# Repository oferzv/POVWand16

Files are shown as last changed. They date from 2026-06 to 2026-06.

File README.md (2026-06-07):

# POVWand16

POVWand16 is a 16 LED persistence-of-vision wand. When the wand is moved
through the air, the firmware flashes a vertical column of LEDs fast enough
that the viewer sees complete text or simple bitmap graphics suspended in the
motion path.

The repository contains both sides of the project:

- Arduino firmware for driving the LED column and selecting messages or
  graphics.
- Autodesk Eagle schematic and board layout files for the custom PCB.
- Manufacturing outputs, including a BOM spreadsheet and Gerber archive.

## Project Overview

The design is based around an Arduino Nano-compatible controller connected to
16 individual LEDs. Each LED has its own 100 ohm series resistor. The firmware
writes directly to the AVR port registers for speed, allowing all 16 LEDs to be
updated as a two-byte column pattern.

A trigger input on Arduino analog pin A4 is used to step through the available
display content. The current firmware alternates between text messages and
graphics. Text can be rendered with either the English font table or the Hebrew
font table stored in program memory.

The hardware is intended to be a self-contained handheld wand. The PCB includes
the Arduino Nano footprint, the LED column, a 9 V battery holder, a power slide
switch, a tactile switch, and several header connectors.

## Repository Layout

```text
.
+-- Firmware
|   +-- README.md
|   +-- POVWand16_SW_heb
|       +-- POVWand16.ino
|       +-- font.h
|       +-- python
|           +-- pandaTestFormat.py
+-- Hardware
|   +-- V1_1
|       +-- Eagle
|       |   +-- POVWand16.brd
|       |   +-- POVWand16.sch
|       +-- Manufacturing
|           +-- BOM
|           |   +-- POVWand16_BOM.xlsx
|           +-- Gerber
|               +-- POVWand16_2020-03-09.zip
+-- README.md
```

## Hardware

The hardware design files live under `Hardware/V1_1`.

Main board elements:

- Arduino Nano 3.0-compatible module footprint.
- 16 through-hole 3 mm LEDs labeled `D1` through `D16`.
- 16 through-hole 100 ohm LED current-limiting resistors labeled `R1` through
  `R16`.
- 9 V battery holder footprint.
- Slide power switch.
- 6 mm momentary tactile switch.
- Additional 1x08 and 1x18 headers for board connections and expansion.

The Eagle files are:

- `Hardware/V1_1/Eagle/POVWand16.sch` - schematic.
- `Hardware/V1_1/Eagle/POVWand16.brd` - PCB layout.

Manufacturing files are:

- `Hardware/V1_1/Manufacturing/BOM/POVWand16_BOM.xlsx` - bill of materials.
- `Hardware/V1_1/Manufacturing/Gerber/POVWand16_2020-03-09.zip` - Gerber
  output for PCB fabrication.

## Firmware

The firmware is an Arduino sketch located at:

```text
Firmware/POVWand16_SW_heb/POVWand16.ino
```

Supporting files:

- `font.h` contains the English and Hebrew font tables in `PROGMEM`.
- `python/pandaTestFormat.py` is a small helper script for converting Hebrew
  text into the character order/encoding expected by the sketch.

The sketch uses Arduino pins 2 through 17 as the 16 LED outputs:

```cpp
const byte LEDpins[] = {2, 3, 4, 5, 6, 7, 8, 9, 10, 11, 12, 13, 14, 15, 16, 17};
```

The trigger input is on pin 18, which corresponds to Arduino A4:

```cpp
const byte triggerPin = 18;
```

Display timing is controlled by three constants:

- `charDelay` - spacing between characters.
- `tColDelay` - spacing between text columns.
- `gColDelay` - spacing between graphic columns.

The current firmware defines six text messages and two graphics. A trigger
press advances through the text messages, then advances through the graphics,
then returns to the first text message.

## Display Content

Text messages are defined in `POVWand16.ino` as `PROGMEM` strings:

```cpp
const char textString01 [] PROGMEM = "ARDIUNO - fqjafdya";
const char textString02 [] PROGMEM = "eqfyfxe jyha eay{q";
const char textString03 [] PROGMEM = "BRAVO!";
const char textString04 [] PROGMEM = "Hello";
const char textString05 [] PROGMEM = "WOW!";
const char textString06 [] PROGMEM = "Amazing";
```

Each message is paired with a font type in the `messages_new` table:

- `HEBFONT` selects the Hebrew font table.
- `ENGFONT` selects the English font table.

Graphics are stored as byte arrays in the `graphic` table. Each displayed
column is represented by two bytes, covering the full 16 LED height.

## Building and Uploading

Open `Firmware/POVWand16_SW_heb/POVWand16.ino` in the Arduino IDE or another
Arduino-compatible build environment.

Recommended target:

- Board: Arduino Nano or compatible.
- Processor: the option matching the installed Nano bootloader.
- Upload method: standard USB serial upload through the Nano.

After upload, power the wand and move it through the air. Use the trigger input
to cycle through the stored text and graphic displays.

## Customization Notes

To change displayed text:

1. Edit the `textStringXX` constants in `POVWand16.ino`.
2. Set each message's font type in `messages_new`.
3. Update `NUMBER_OF_ELEMENTS` if the number of messages changes.

To change graphics:

1. Edit the byte arrays in the `graphic` table.
2. Keep each graphic encoded as pairs of bytes per column.
3. Adjust the timing constants if the image appears stretched or compressed
   while waving the wand.

To change LED wiring:

1. Update `LEDpins` if using the slower `digitalWrite` helper path.
2. Update `setPorts()` if changing the direct AVR port mapping used by the
   main display loop.

## Attribution

The firmware is based on the JolliPOV Stick Arduino code from the Instructables
project
[Arduino Based POV Display Stick - JolliPOV Stick](https://www.instructables.com/Arduino-Based-POV-Display-Stick-JolliPOV-Stick/)
by [jollifactory](https://www.instructables.com/member/jollifactory/).

Credit and thanks to the original author for publishing the JolliPOV Stick
project instructions and example firmware.

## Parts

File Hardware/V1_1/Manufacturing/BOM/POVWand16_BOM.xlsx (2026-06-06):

povTest BOM
# | Qty | Parts | MF | MPN | PRICE | TOTAL | VALUE | FOOTPRINT | DESCRIPTION
1 | 1 | SW1 | C&K | PTS645SM43-2 LFS | $0.040 | $0.04 |  | 6.00mm x 6.00mm | SWITCH TACTILE SPST-NO 0.05A 12V | https://www.taydaelectronics.com/electromechanical/switches-key-pad/tact-switch/tact-switch-6-6mm-7mm-through-hole-spst-no-1.html
2 | 16 | R1, R2, R3, R4, R5, R6, R7, R8, R9, R10, R11, R12, R13, R14, R15, R16 |  |  | $0.012 | $0.19 | 100Ohm | T/H |  | https://www.taydaelectronics.com/resistors/1-4w-metal-film-resistors/test-group-2.html
3 | 16 | D1, D2, D3, D4, D5, D6, D7, D8, D9, D10, D11, D12, D13, D14, D15, D16 |  |  | $0.02 | $0.32 | 3mm | RADIAL 3MM |  | https://www.taydaelectronics.com/leds/round-leds/3mm-leds/led-3mm-red.html
4 | 2 |  |  |  | $0.12 | $0.24 |  |  | 15 PIN 2.54MM SINGLE ROW FEMALE PIN HEADER | https://www.taydaelectronics.com/connectors-sockets/pin-headers/15-pin-2-54-mm-single-row-female-pin-header.html
5 | 1 | M1 |  |  | $3.690 | $3.69 |  |  | NANO 3.0 CONTROLLER COMPATIBLE WITH ARDUINO NANO CH340 USB DRIVER | https://www.taydaelectronics.com/nano-3-0-controller-compatible-with-arduino-nano-ch340-usb-driver.html
6 | 1 | BT1 | MPD _Memory | BH9VPC | $0.470 | $0.47 |  |  | Battery Holder _Open_ 9V 1 Cell PC Pin | https://www.taydaelectronics.com/9v-battery-holder-6.html
7 | 1 | S1 |  | SS12F44G5 | $0.050 | $0.05 |  |  | SLIDE SWITCH 1P2T THROUGH HOLE 0.5A 50VDC | https://www.taydaelectronics.com/electromechanical/switches-key-pad/slide-switch/slide-switch-1p2t-through-hole-0-5a-50vdc.html
 |  |  |  |  |  | $5.00

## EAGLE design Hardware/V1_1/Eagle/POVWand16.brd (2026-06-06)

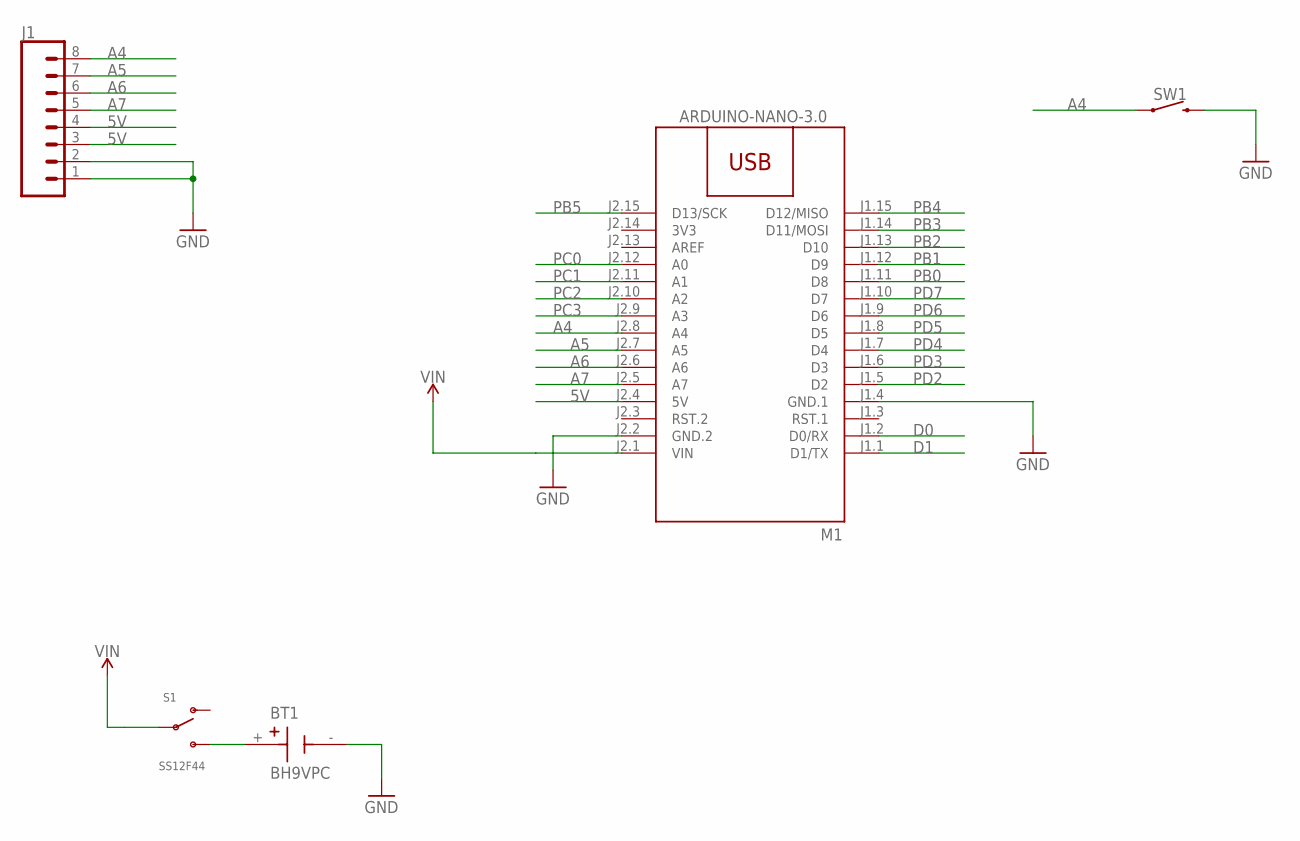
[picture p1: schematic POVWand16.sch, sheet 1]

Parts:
BT1: BH9VPC; BAT_BH9VPC
J1: CONN_08"; 1X08
M1: ARDUINO-NANO-3.0
S1: SS12F44; SS12F44G5
SW1: MOMENTARY-SWITCH-SPST_6X6MM; TACT_SW_PTH_6.0MM

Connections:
3V3: M1.J2.14 (3V3)
5V: J1.3, J1.4, M1.J2.4 (5V)
A4: J1.8, M1.J2.8 (A4), SW1.1, SW1.2 (1)
A5: J1.7, M1.J2.7 (A5)
A6: J1.6, M1.J2.6 (A6)
A7: J1.5, M1.J2.5 (A7)
D0: M1.J1.2 (D0/RX); also elsewhere on the board
D1: M1.J1.1 (D1/TX); also elsewhere on the board
GND: BT1.-, J1.1, J1.2, M1.J1.4 (GND.1), M1.J2.2 (GND.2), SW1.3 (2), SW1.4 (2); also elsewhere on the board
unnamed: BT1.+, S1.3 (S)
PB0: M1.J1.11 (D8); also elsewhere on the board
PB1: M1.J1.12 (D9); also elsewhere on the board
PB2: M1.J1.13 (D10); also elsewhere on the board
PB3: M1.J1.14 (D11/MOSI); also elsewhere on the board
PB4: M1.J1.15 (D12/MISO); also elsewhere on the board
PB5: M1.J2.15 (D13/SCK); also elsewhere on the board
PC0: M1.J2.12 (A0); also elsewhere on the board
PC1: M1.J2.11 (A1); also elsewhere on the board
PC2: M1.J2.10 (A2); also elsewhere on the board
PC3: M1.J2.9 (A3); also elsewhere on the board
PD2: M1.J1.5 (D2); also elsewhere on the board
PD3: M1.J1.6 (D3); also elsewhere on the board
PD4: M1.J1.7 (D4); also elsewhere on the board
PD5: M1.J1.8 (D5); also elsewhere on the board
PD6: M1.J1.9 (D6); also elsewhere on the board
PD7: M1.J1.10 (D7); also elsewhere on the board
VIN: M1.J2.1 (VIN), S1.2

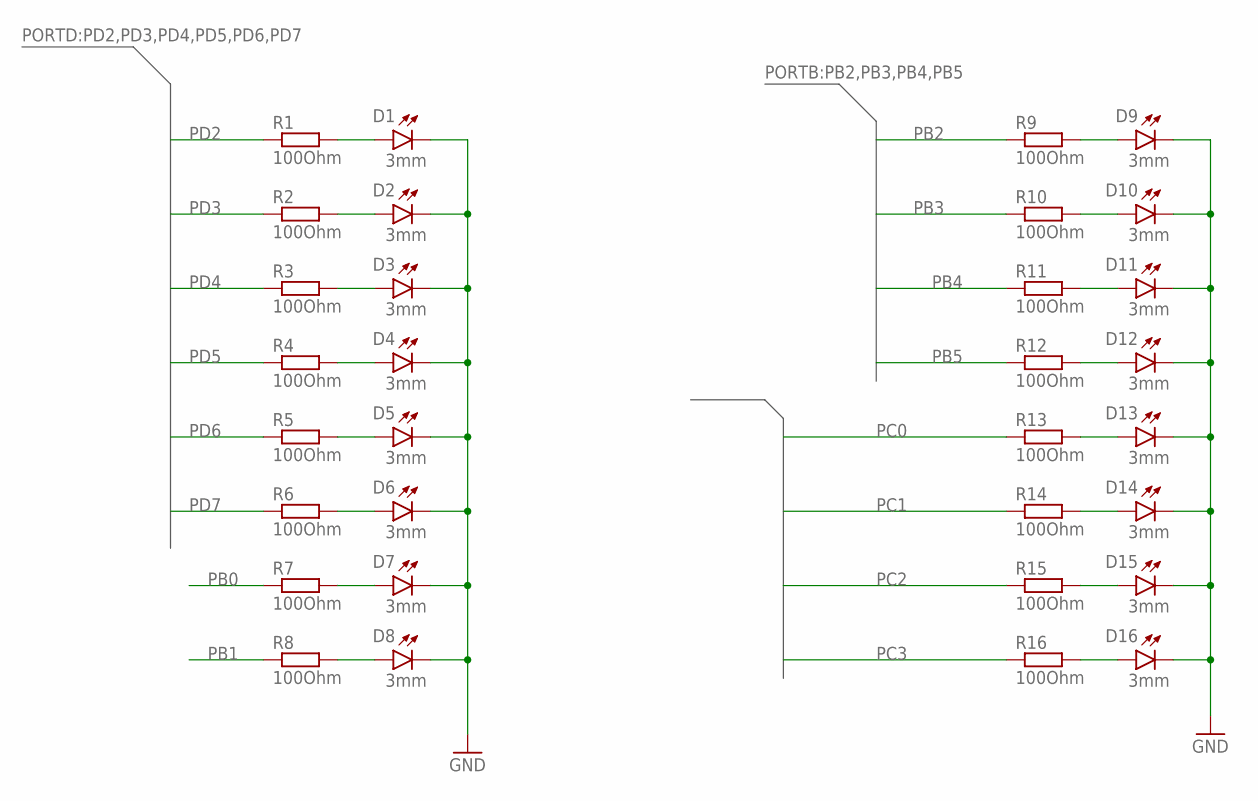
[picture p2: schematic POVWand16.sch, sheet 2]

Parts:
D1, D2, D3, D4, D5, D6, D7, D8, D9, D10, D11, D12, D13, D14, D15, D16: 3mm; LED3MM
R1, R2, R3, R4, R5, R6, R7, R8, R9, R10, R11, R12, R13, R14, R15, R16: 100Ohm; 0207/7

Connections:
GND: D1.K (C), D2.K (C), D3.K (C), D4.K (C), D5.K (C), D6.K (C), D7.K (C), D8.K (C), D9.K (C), D10.K (C), D11.K (C), D12.K (C), D13.K (C), D14.K (C), D15.K (C), D16.K (C); also elsewhere on the board
unnamed: D1.A, R1.2
unnamed: D2.A, R2.2
unnamed: D3.A, R3.2
unnamed: D4.A, R4.2
unnamed: D5.A, R5.2
unnamed: D6.A, R6.2
unnamed: D7.A, R7.2
unnamed: D8.A, R8.2
unnamed: D9.A, R9.2
unnamed: D10.A, R10.2
unnamed: D11.A, R11.2
unnamed: D12.A, R12.2
unnamed: D13.A, R13.2
unnamed: D14.A, R14.2
unnamed: D15.A, R15.2
unnamed: D16.A, R16.2
PB0: R7.1; also elsewhere on the board
PB1: R8.1; also elsewhere on the board
PB2: R9.1; also elsewhere on the board
PB3: R10.1; also elsewhere on the board
PB4: R11.1; also elsewhere on the board
PB5: R12.1; also elsewhere on the board
PC0: R13.1; also elsewhere on the board
PC1: R14.1; also elsewhere on the board
PC2: R15.1; also elsewhere on the board
PC3: R16.1; also elsewhere on the board
PD2: R1.1; also elsewhere on the board
PD3: R2.1; also elsewhere on the board
PD4: R3.1; also elsewhere on the board
PD5: R4.1; also elsewhere on the board
PD6: R5.1; also elsewhere on the board
PD7: R6.1; also elsewhere on the board

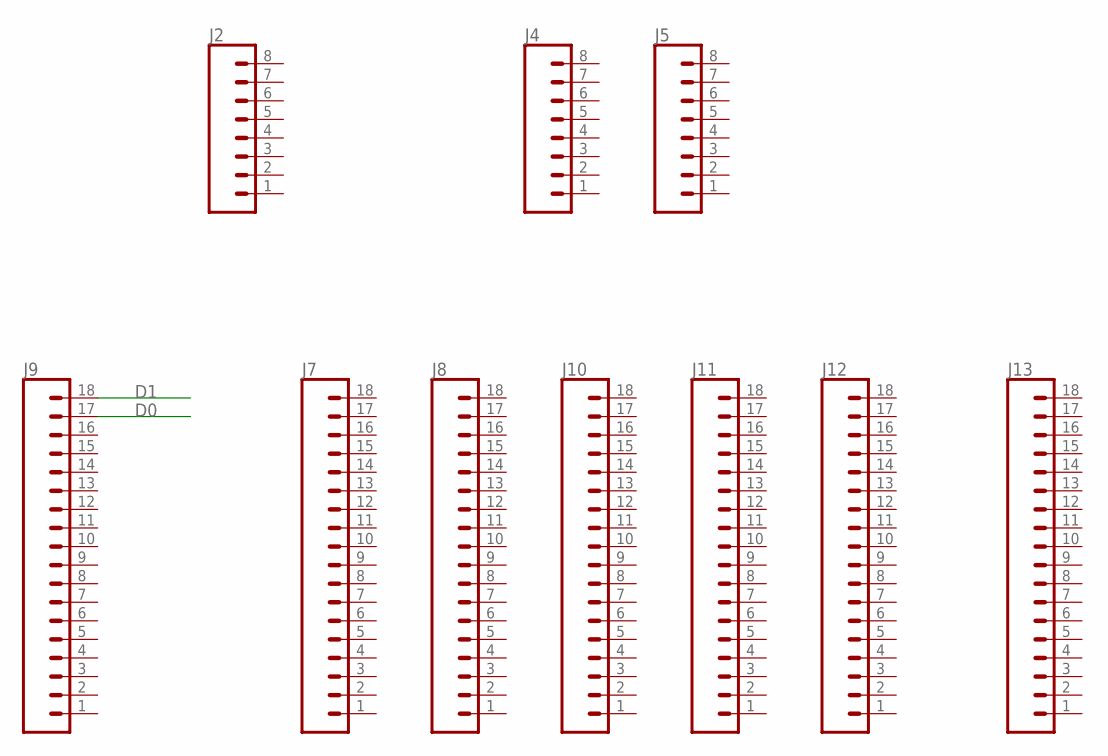
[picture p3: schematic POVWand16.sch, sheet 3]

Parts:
J2, J4, J5: CONN_08"; 1X08
J7, J8, J9, J10, J11, J12, J13: CONN_18; 1X18

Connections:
D0: J9.17; also elsewhere on the board
D1: J9.18; also elsewhere on the board

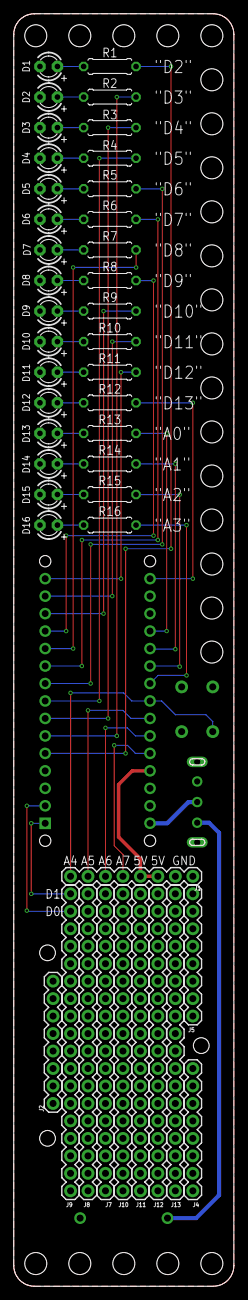
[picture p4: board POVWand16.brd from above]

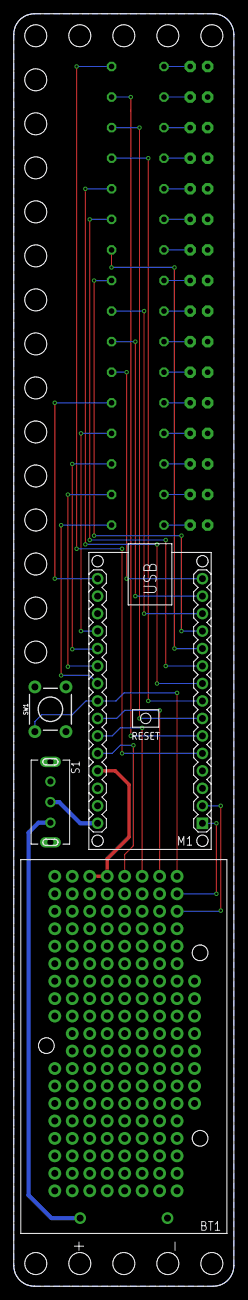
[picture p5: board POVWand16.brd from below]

Board: 2 copper layers, 32.0 x 185.0 mm, 47 parts (4 on the bottom side), 42 nets.

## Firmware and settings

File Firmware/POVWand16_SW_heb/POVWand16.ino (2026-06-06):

// Code Example for JF jolliPOV Stick kit example Demo #1 Ver 1.0

// This Arduino sketch works with JF jolliPOV Stick handheld and waving it to and forth to display text and graphics
// For this example, set jumper to position B for text and graphics display using Main PCB's 16 LEDs
// Checkout instructable available at https://www.instructables.com/id/Arduino-Based-POV-Display-Stick-JolliPOV-Stick/

#define HEBFONT 0
#define ENGFONT 1


byte NumberBytesChar = 21;
#include "font.h"

// Define the Arduino LED pins in use
const byte LEDpins[] = {2, 3, 4, 5, 6, 7, 8, 9, 10, 11, 12, 13, 14, 15, 16, 17}; // jolliPOV Stick Main PCB LED Pins

// Number of LEDs used
int LedCount() {
  return sizeof(LEDpins) / sizeof(*LEDpins);
}


// Define graphics 64 (Width) X 16 (Height)  ***********************************************************************************************************************
byte graphic[2][128] = {
  // Hearts 64 X 16
//  {
//    0x00, 0x00, 0xf0, 0x00, 0xf8, 0x01, 0x0c, 0x03, 0x06, 0x06, 0x06, 0x0c, 0x06, 0x18, 0x0c, 0x30, 0x18, 0x60, 0x0c, 0x30, 0x06, 0x18, 0x06, 0x0c, 0x06, 0x06, 0x0c, 0x03, 0xf8, 0x01, 0xf0, 0x00, 0x00, 0x00, 0x00, 0x00, 0xc0, 0x01, 0xe0, 0x03, 0xf0, 0x07, 0xf0, 0x0f, 0xe0, 0x1f, 0xc0, 0x3f, 0xe0, 0x1f, 0xf0, 0x0f, 0xf0, 0x07, 0xe0, 0x03, 0xc0, 0x01, 0x00, 0x00, 0x00, 0x00, 0x00, 0x00, 0x00, 0x00, 0x00, 0x00, 0x00, 0x00, 0x00, 0x00, 0xf0, 0x00, 0x08, 0x01, 0x04, 0x02, 0x02, 0x04, 0x02, 0x08, 0x02, 0x10, 0x04, 0x20, 0x08, 0x40, 0x04, 0x20, 0x02, 0x10, 0x02, 0x08, 0x02, 0x04, 0xf4, 0x02, 0xf8, 0x01, 0xfc, 0x03, 0xfe, 0x07, 0xfe, 0x0f, 0xfe, 0x1f, 0xfc, 0x3f, 0xf8, 0x7f, 0xfc, 0x3f, 0xfe, 0x1f, 0xfe, 0x0f, 0xfe, 0x07, 0xfc, 0x03, 0xf8, 0x01, 0xf0, 0x00, 0x00, 0x00
//  },

  // Arrows 64 x 16
  {
    0x00, 0x00, 0x00, 0x00, 0xc0, 0x01, 0xc0, 0x01, 0xc0, 0x01, 0xc0, 0x01, 0xc0, 0x01, 0xc0, 0x01, 0xc0, 0x01, 0xc0, 0x01, 0xf8, 0x0f, 0xf0, 0x07, 0xe0, 0x03, 0xc0, 0x01, 0x80, 0x00, 0x00, 0x00, 0x00, 0x00, 0x00, 0x00, 0xe0, 0x03, 0xe0, 0x03, 0xe0, 0x03, 0xe0, 0x03, 0xe0, 0x03, 0xe0, 0x03, 0xe0, 0x03, 0xe0, 0x03, 0xe0, 0x03, 0xe0, 0x03, 0xe0, 0x03, 0xe0, 0x03, 0xe0, 0x03, 0xfe, 0x3f, 0xfc, 0x1f, 0xf8, 0x0f, 0xf0, 0x07, 0xe0, 0x03, 0xc0, 0x01, 0x80, 0x00, 0x00, 0x00, 0x00, 0x00, 0x00, 0x00, 0xf0, 0x07, 0xf0, 0x07, 0xf0, 0x07, 0xf0, 0x07, 0xf0, 0x07, 0xf0, 0x07, 0xf0, 0x07, 0xf0, 0x07, 0xf0, 0x07, 0xf0, 0x07, 0xf0, 0x07, 0xf0, 0x07, 0xf0, 0x07, 0xf0, 0x07, 0xff, 0x7f, 0xfe, 0x3f, 0xfc, 0x1f, 0xf8, 0x0f, 0xf0, 0x07, 0xe0, 0x03, 0xc0, 0x01, 0x80, 0x00, 0x00, 0x00
  },

  {
    0x00, 0x00, 0x00, 0x00, 0xe4, 0x00, 0x02, 0x00, 0x02, 0x00, 0xfe, 0x00, 0x00, 0x00, 0x08, 0x00, 0xe4, 0x03, 0x22, 0x00, 0x22, 0x00, 0x1c, 0x00, 0x00, 0x00, 0x0e, 0x00, 0x00, 0x00, 0x04, 0x00, 0x02, 0x00, 0x82, 0x01, 0x42, 0x00, 0x4c, 0x00, 0x30, 0x00, 0x00, 0x00, 0x02, 0x01, 0x12, 0x01, 0xb2, 0x00, 0x4c, 0x00, 0x00, 0x00, 0x00, 0x00, 0x00, 0x00, 0x00, 0x00, 0x00, 0x00, 0x00, 0x00,0x00, 0x00, 0x00, 0x00, 0xe4, 0x00, 0x02, 0x00, 0x02, 0x00, 0xfe, 0x00, 0x00, 0x00, 0x08, 0x00, 0xe4, 0x03, 0x22, 0x00, 0x22, 0x00, 0x1c, 0x00, 0x00, 0x00, 0x0e, 0x00, 0x00, 0x00, 0x04, 0x00, 0x02, 0x00, 0x82, 0x01, 0x42, 0x00, 0x4c, 0x00, 0x30, 0x00, 0x00, 0x00, 0x02, 0x01, 0x12, 0x01, 0xb2, 0x00, 0x4c, 0x00, 0x00, 0x00, 0x00, 0x00, 0x00, 0x00, 0x00, 0x00, 0x00, 0x00, 0x00, 0x00

  
  }

  

};


const int NUMBER_OF_ELEMENTS = 6;

const char textString01 [] PROGMEM = "ARDIUNO - fqjafdya";
const char textString02 [] PROGMEM = "eqfyfxe jyha eay{q";
const char textString03 [] PROGMEM = "BRAVO!";
const char textString04 [] PROGMEM = "Hello";
const char textString05 [] PROGMEM = "WOW!";
const char textString06 [] PROGMEM = "Amazing";


struct message {
  char * text;
  byte fontType;
};

const message messages_new[NUMBER_OF_ELEMENTS] PROGMEM = {
  {textString01, HEBFONT},
  {textString02, HEBFONT},
  {textString03, ENGFONT},
  {textString04, ENGFONT},
  {textString05, ENGFONT},
  {textString06, ENGFONT}
};




unsigned long startTime = millis();
unsigned long elapsedTime = 30;     // 0.8 seconds lapse before re-triggering of display enabled

const byte triggerPin = 18;            //A4 connected to ball tilt switch
const int charDelay = 3000;          // Space between characters
const int tColDelay = 900;           // Space between text columns
const int gColDelay = 800;           // Space between graphic/pattern columns

byte textMsgSelection = 1;
byte graphicSelection = 1;
byte max_graphicCount = sizeof(graphic) / sizeof(graphic[0]);

boolean displayGraphics = false;
boolean firstByte = true;


int buttonState = HIGH;
int lastButtonState = HIGH;
unsigned long lastDebounceTime = 0;  // the last time the output pin was toggled
unsigned long debounceDelay = 50;    // the debounce time; increase if the output flickers

//****************************************************************************************************************************************************
void setup()
{


  Serial.begin(115200);
  for (int i = 0; i < LedCount(); i++) {
    pinMode(LEDpins[i], OUTPUT);
    digitalWrite(LEDpins[i], HIGH);
    delay(75);
    digitalWrite(LEDpins[i], LOW);
    delay(75);
  }

  for (int z=0; z<2; z++) {
    setPorts(255,255);
    delay(150);
    setPorts(0,0);
    delay(150);
    
  }
    
  pinMode(triggerPin, INPUT_PULLUP);

}

//****************************************************************************************************************************************************
void loop()
{

  // read the state of the switch into a local variable:
  int reading = digitalRead(triggerPin);

  if (reading != lastButtonState) {
    // reset the debouncing timer
    lastDebounceTime = millis();
  }

  if ((millis() - lastDebounceTime) > debounceDelay) {
    // if the button state has changed:
    if (reading != buttonState) {
      buttonState = reading;

      // only toggle the LED if the new button state is HIGH
      if (buttonState == LOW) {
        setPorts(255, 255);

        if (displayGraphics == false)     // Display text messages
        {
          textMsgSelection++;

          if (textMsgSelection > NUMBER_OF_ELEMENTS)
          {
            textMsgSelection = 1;
            graphicSelection = 1;
            displayGraphics = true;
          }
        }
        else
        {
          graphicSelection++;

          if (graphicSelection > max_graphicCount)
          {
            textMsgSelection = 1;
            displayGraphics = false;
          }
        }
        delay(500);
        setPorts(0, 0);
      } // end if (buttonState == LOW)
    } //end if (reading != buttonState)
  } //end if

  lastButtonState = reading;

  if ((millis() - startTime) > elapsedTime)
  {
    if (displayGraphics == false)     // Display text messages
    {
      char * ptr = (char *) pgm_read_word (&messages_new[textMsgSelection - 1].text);
      char buffer [80];
      strcpy_P (buffer, ptr);
      byte fontType =  pgm_read_word (&messages_new[textMsgSelection - 1].fontType);


      for (int k = 0; k < strlen(buffer); k++) {
        if (fontType == HEBFONT)
          printLetterLarge(buffer[k], MyFontHeb);
        if (fontType == ENGFONT)
          printLetterLarge(buffer[k], MyFont);
      } //end for
    }
    else
    {
      firstByte = true;

      for (int k = 0; k < (sizeof(graphic) / max_graphicCount); k += 2)
      {
        setPorts(graphic[graphicSelection - 1][k], graphic[graphicSelection - 1][k + 1]);
        //ApplyGraphic(k);
        delayMicroseconds(gColDelay);
      }

    } //end if

    startTime = millis();
  } //end if elapsed time
}



//****************************************************************************************************************************************************
void printLetterLarge(char ch, unsigned short * font)
{
  // Make sure the character is within the alphabet bounds (defined by the font.h file)
  // If it's not, make it a blank character
  if (ch < 32 || ch > 126)
    ch = 32;

  // Step through each byte of the character array
  
  for (int i = 0; i < pgm_read_byte(&(font[((ch - 32) * NumberBytesChar)])); i++)
  {
    byte b = pgm_read_byte(&(font[((ch - 32) * NumberBytesChar) + 1 + (i * 2)]));
    byte b2 = pgm_read_byte(&(font[((ch - 32) * NumberBytesChar) + 2 + (i * 2)]));
    setPorts(b, b2);

    //    PORTD = (PORTD & B11) |  (b << 2);
    //    PORTB = b >> 6 | ((b2 & B1111) << 2);
    //    PORTC = (PORTC & B11110000) | b2 >> 4;

    // Space between columns
    delayMicroseconds(tColDelay);
  }

  // Clear LEDs
  setPorts(0, 0);
  //  PORTD = (PORTD & B11) ;
  //  PORTB = 0;
  //  PORTC = (PORTC & B11110000) ;

  // Space between characters
  delayMicroseconds(charDelay);
}

//***********************************************************************************************************************
void setPorts(byte data1, byte data2) {
  PORTD = (PORTD & B11) |  (data1 << 2);
  PORTB = data1 >> 6 | ((data2 & B1111) << 2);
  PORTC = (PORTC & B11110000) | data2 >> 4;
}


//***********************************************************************************************************************
int GraphicLength()
{
  return (sizeof(graphic[0]) / sizeof(*graphic[0]));
}


//***********************************************************************************************************************
void ApplyGraphic(int position)
{
  if (firstByte == true)
  {
    for (byte i = 0, bit = 1; i < 8; ++i, bit <<= 1)
    {
      firstByte = false;
      digitalWrite( LEDpins[i], (graphic[graphicSelection - 1][position]&bit) ? HIGH : LOW);
    }
  }
  else
  {
    for (byte i = 8, bit = 1; i < 16; ++i, bit <<= 1)
    {
      firstByte = true;
      digitalWrite( LEDpins[i], (graphic[graphicSelection - 1][position]&bit) ? HIGH : LOW);
    }
  }
}

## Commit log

2026-06-06 Ignore Excel temporary files
    [POVWand16.brd, POVWand16.sch, POVWand16_BOM.xlsx]
2026-06-06 Add Hebrew string processing script and update README
    - Introduced a new Python script `pandaTestFormat.py` for processing Hebrew strings.
    - The script accepts a Hebrew string as input, decodes it, and outputs a modified version.
    - Added a README file to provide context and credit for the firmware based on the JolliPOV Stick project.
    - Included a new BOM Excel file for manufacturing reference.

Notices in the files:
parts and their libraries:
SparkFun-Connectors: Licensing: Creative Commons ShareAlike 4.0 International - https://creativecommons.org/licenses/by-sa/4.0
